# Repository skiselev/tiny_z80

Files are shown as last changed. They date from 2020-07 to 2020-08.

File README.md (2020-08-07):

# Tiny Z80
Business Card Sized Zilog Z80 Single Board Computer

## Table of Content
* [Introduction](#introduction)
* [Specifications](#specifications)
* [Hardware Documentation](#hardware-documentation)
  * [Schematic and PCB Layout](#schematic-and-pcb-layout)
  * [Connectors and Jumpers](#connectors-and-jumpers)
  * [Bill of Materials](#bill-of-materials)
* [Firmware Documentation](#firmware-documentation)
  * [BIOS and OS](#bios-and-os)
  * [SPLD Fuse Map](#spld-fuse-map)
* [Release Notes](#release-notes)
  * [Changes](#changes)
  * [Known Issues](#known-issues)
  * [Wishlist](#wishlist)

## Introduction
Tiny Z80 is a business card sized (size?!) single board computer (SBC). It is mostly compatible with [Easy Z80](https://github.com/skiselev/easy_z80), and offers similar capabilities, including 512 KiB of battery-backed SRAM, 512 KiB Flash ROM, Z80 SIO and Z80 CTC (integrated in Z80 EIPC). Tiny Z80 includes a USB to Serial converter IC on board connected to one of the SIO ports, for ease of use with modern computers. The glue logic, including the memory paging registers is implemented using Altera MAX7000AE CPLD.

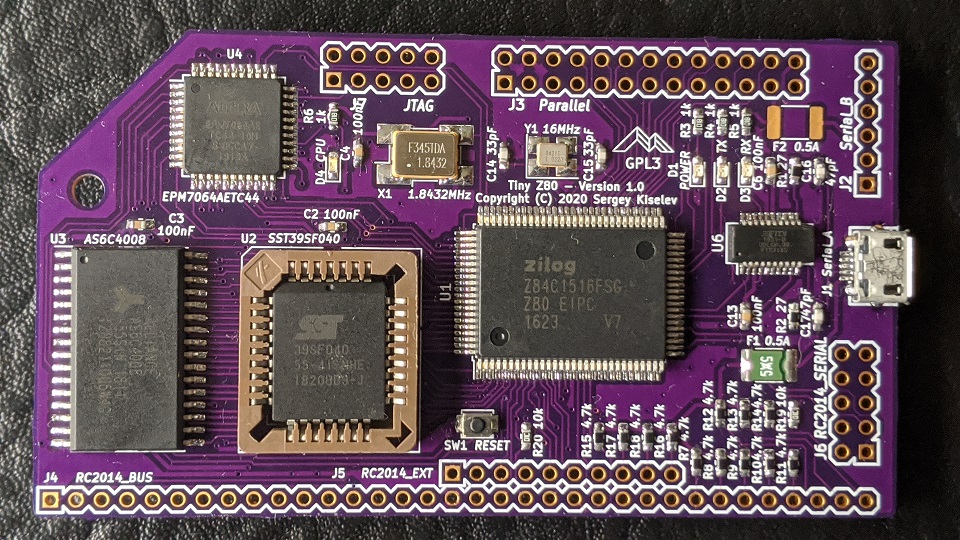
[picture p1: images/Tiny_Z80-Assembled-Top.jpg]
Tiny Z80 Assembled Board Top View


## Specifications
* Processor: Zilog Z80 EIPC - Z84C15, includes Z80 CPU, Z80 SIO, Z80 PIO, and Z80 CTC
* Memory: 512 KiB battery-backed SRAM, 512 KiB Flash ROM
* Input/Output:
  * Dual RS232 serial ports, implemented using Z80 SIO integrated into Z80 EIPC
  * FT231XS USB to Serial converter connected to SIO Port A
  * Two 8-bit parallel ports, implemented using Z80 PIO integrated into Z80 EIPC
  * User controllable LED
* Bus: [RC2014](https://rc2014.co.uk/) compatible
* Microprocessor Supervisor:
  * Reset generation
  * SRAM battery backup
  * Power failure NMI
  * Watchdog (optional)

## Hardware Documentation

### Schematic and PCB Layout

[Schematic - Version 1.0](KiCad/Tiny_Z80-Schematic-1.0.pdf)

[PCB Layout - Version 1.0](KiCad/Tiny_Z80-Board-1.0.pdf)

### Connectors and Jumpers

#### J1 - Serial_A - USB Serial
Pin  | Signal Name | Description
---- | ----------- | -----------
1    | VBUS        | Power Supply - +5V
2    | D-          | USB Data -
3    | D+          | USB Data +
4    | NC          | Not Connected
5    | GND         | Ground

#### J2 - Serial_B - FTDI Header - TTL Level
Pin  | Signal Name | Description
---- | ----------- | -----------
1    | GND         | Ground
2    | RTS         | RS232 / Request to Send
3    | VSER        | Power Supply - +5V (Optional, if F2 is installed)
4    | RXD         | RS232 / Receive
5    | TXD         | RS232 / Transmit
6    | CTS         | RS232 / Clear to Send

#### J3 - Parallel - PIO
Pin  | Signal Name | Description         | Pin  | Signal Name | Description
---- | ----------- | ------------------- | ---- | ----------- | -----------
1    | VCC         | Power Supply - +5V  | 2    | GND         | Ground
3    | PA0         | Port A - Data 0     | 4    | GND         | Ground
5    | PA1         | Port A - Data 1     | 6    | /BSTB       | Port B - Strobe 
7    | PA2         | Port A - Data 2     | 8    | BRDY        | Port B - Ready
9    | PA3         | Port A - Data 3     | 10   | PB7         | Port B - Data 7
11   | PA4         | Port A - Data 4     | 12   | PB6         | Port B - Data 6
13   | PA5         | Port A - Data 5     | 14   | PB5         | Port B - Data 5
15   | PA6         | Port A - Data 6     | 16   | PB4         | Port B - Data 4
17   | PA7         | Port A - Data 7     | 18   | PB3         | Port B - Data 3
19   | ARDY        | Port A - Ready      | 20   | PB2         | Port B - Data 2
21   | /ASTB       | Port A - Strobe     | 22   | PB1         | Port B - Data 1
23   | GND         | Ground              | 24   | PB0         | Port B - Data 0
25   | GND         | Ground              | 26   | VCC         | Power Supply - +5V

#### J4, J5, J6 - RC2014 Bus
Pin   | Signal Name | Description         | Pin  | Signal Name | Description
----- | ----------- | ------------------- | ---- | ----------- | -----------
J4-1  | A15         | Address A15; Output |      |             |
J4-2  | A14         | Address A14; Output |      |             |
J4-3  | A13         | Address A13; Output |      |             |
J4-4  | A12         | Address A12; Output |      |             |
J4-5  | A11         | Address A11; Output |      |             |
J4-6  | A10         | Address A10; Output |      |             |
J4-7  | A9          | Address A9; Output  |      |             |
J4-8  | A8          | Address A8; Output  |      |             |
J4-9  | A7          | Address A7; Output  |      |             |
J4-10 | A6          | Address A6; Output  |      |             |
J4-11 | A5          | Address A5; Output  |      |             |
J4-12 | A4          | Address A4; Output  |      |             |
J4-13 | A3          | Address A3; Output  |      |             |
J4-14 | A2          | Address A2; Output  |      |             |
J4-15 | A1          | Address A1; Output  |      |             |
J4-16 | A0          | Address A0; Output  |      |             |
J4-17 | GND         | Ground              | J5-1 | GND         | Ground
J4-18 | VCC         | Power Supply - +5V  | J5-2 | VCC         | Power Supply - +5V
J4-19 | /M1         | Machine Cycle One; Output | J5-3| /RFSH | DRAM refresh; Output
J4-20 | /RESET      | Reset; Output       | J5-4 | N/C         | Not connected
J4-21 | CPU_CLK     | CPU Clock; Output   | J5-5 | UART_CLK    | UART Clock (1.8432 MHz); Output
J4-22 | /INT        | Interrupt; Input    | J5-6 | /BUSACK     | DMA Bus Acknowledge; Output
J4-23 | /MREQ       | Memory Request; Output | J5-8 | /HALT    | Halt; Output
J4-24 | /WR         | Write Request; Output | J5-9 | /WAIT     | Wait; Input
J4-25 | /RD         | Read Request; Output | J5-10 | /NMI      | Non-maskable Interrupt; Input
J4-26 | /IORQ       | Input/Output Request; Output | |         |
J4-27 | D0          | Data D0; Input/Output |    |             |
J4-28 | D1          | Data D1; Input/Output |    |             |
J4-29 | D2          | Data D2; Input/Output |    |             |
J4-30 | D3          | Data D3; Input/Output |    |             |
J4-31 | D4          | Data D4; Input/Output |    |             |
J4-32 | D5          | Data D5; Input/Output |    |             |
J4-33 | D6          | Data D6; Input/Output |    |             |
J4-34 | D7          | Data D7; Input/Output |    |             |
J6-1  | TXDA        | Channel A, Transmit Data; Output | J6-2 | TXDB | Channel B, Transmit Data; Output
J6-3  | RXDA        | Channel A, Receive Data; Input   | J6-4 | RXDB | Channel B, Receive Data; Input
J6-5  | USR1        | User Pin 1, Not connected | J6-6 | USR5  | User Pin 5, Not connected 
J6-7  | IEI         | Interrupt Enable Input  | J6-8 | USR6    | User Pin 6, Not connected 
J6-9  | IEO         | Interrupt Enable Output | J6-10 | USR7    | User Pin 7, Not connected 

#### J7 - JTAG - CPLD
Pin  | Signal Name | Description      | Pin  | Signal Name | Description
---- | ----------- | ---------------- | ---- | ----------- | ----------------
1    | TCK         | Test Clock       | 2    | GND         | Ground
3    | TDO         | Test Data Output | 4    | 3.3V        | Power Supply - +3.3V
5    | TMS         | Test Mode Select | 6    | NC          | No Connect
7    | NC          | No Connect       | 8    | NC          | No Connect
9    | TDI         | Test Data Input  | 10   | GND         | Ground

#### JP1 - Serial Channel A Clock Select
Position        | Description
--------------- | -----------
*1-2 (default)* | 1.8432 MHz (115200 bps if using x16 mode)
2-3             | Programmable using CTC channel 0

#### JP2 - Serial Channel B Clock Select
Position        | Description
--------------- | -----------
*1-2 (default)* | 1.8432 MHz (115200 bps if using x16 mode)
2-3             | Programmable using CTC channel 1

#### JP3 - LDO Bypass
Solder instead of U7 LDO when using a 5V CPLD

#### JP4 - RAM_CS, JP5 - VRAM
Solder when not using U5 CPU Supervisor to connect RAM_CS and VCC directly to the SRAM IC

### Bill of Materials

#### Version 1.0

[Tiny Z80 project on Mouser.com](https://www.mouser.com/ProjectManager/ProjectDetail.aspx?AccessID=d29f509257) - View and order all components except of the PCB.

[Tiny Z80 project on OSH Park](https://oshpark.com/shared_projects/C0KRm6BH) - View and order the PCB.

Component type     | Reference | Description                                 | Quantity | Possible sources and notes 
------------------ | --------- | ------------------------------------------- | -------- | --------------------------
PCB                |           | Tiny Z80 PCB - Version 1.0                  | 1        | Order from a PCB manufacturer of your choice using provided Gerber or KiCad files
Battery Holder     | BT1       | CR2032 Keystone Electronics 534-1058        | 1        | Mouser [534-1058](https://www.mouser.com/ProductDetail/534-1058)
Battery            | BT1       | CR2032                                      | 1        | 
Capacitor          | C1 - C13  | 100nF 0603 SMT                              | 13       | Mouser [77-VJ0603Y104JXJPBC](https://www.mouser.com/ProductDetail/77-VJ0603Y104JXJPBC)
Capacitor          | C14, C15  | 33pF 0603 SMT                               | 2        | Mouser [77-VJ0603A330JXACBC](https://www.mouser.com/ProductDetail/77-VJ0603A330JXACBC)
Capacitor          | C16, C17  | 47pF 0603 SMT                               | 2        | Mouser [77-VJ0603A470JXACBC](https://www.mouser.com/ProductDetail/77-VJ0603A470JXACBC)
Capacitor          | C18       | 10nF	0603 SMT                               | 1        | Mouser [77-V0603Y103KXJAC31X](https://www.mouser.com/ProductDetail/77-V0603Y103KXJAC31X)
Capacitor          | C20, C19  | 10uF	1210 SMT                               | 2        | Mouser [581-TAJB106K020SNJ](https://www.mouser.com/ProductDetail/581-TAJB106K020SNJ)
Capacitor          | C21       | 47uF	SMT                                    | 1        | Mouser [581-TAJC476K016TNJ](https://www.mouser.com/ProductDetail/581-TAJC476K016TNJ)
LED                | D1        | 0603 SMT Power/Green                        | 1        | Mouser [78-VLMG1300-GS08](https://www.mouser.com/ProductDetail/78-VLMG1300-GS08)
LED                | D2        | 0603 SMT TX/Red                             | 1        | Mouser [78-VLMS1300-GS08](https://www.mouser.com/ProductDetail/78-VLMS1300-GS08), [78-VLMO1300-GS08](https://www.mouser.com/ProductDetail/78-VLMO1300-GS08)
LED                | D3        | 0603 SMT RX/Yellow                          | 1        | Mouser [78-VLMY1300-GS08](https://www.mouser.com/ProductDetail/78-VLMY1300-GS08)
LED                | D4        | 0603 SMT CPU/Blue                           | 1        | Mouser []()
Polyfuse           | F2, F1    | 0.5A	SMT                                    | 2        | Mouser [650-MINISMDC050F-2](https://www.mouser.com/ProductDetail/650-MINISMDC050F-2) 
Connector          | J1        | Mini USB B                                  | 1        | Mouser [649-10118194-0001LF](https://www.mouser.com/ProductDetail/649-10118194-0001LF)
Connector          | J2        | Pin Header 1x6                              | 1        | 
Connector          | J3        | Pin Header 2x13                             | 1        | 
Connector          | J4, J5    | Pin Header 2x34, Right Angle                | 1        | Mouser [571-9-103326-0](https://www.mouser.com/ProductDetail/571-9-103326-0) Note: Cut to 34 pin, remove extra pins. Use remaining 2x6 piece for J6
Connector          | J6, J7    | Pin Header 2x5                              | 2        | 
Resistor           | R1, R2    | 27	Ohm 0603 SMT                             | 2        | Mouser [71-CRCW0603-27-E3](https://www.mouser.com/ProductDetail/71-CRCW0603-27-E3)
Resistor           | R3 - R6   | 1 kOhm 0603 SMT                             | 4        | Mouser [71-CRCW0603-1.0K-E3](https://www.mouser.com/ProductDetail/71-CRCW0603-1.0K-E3)
Resistor           | R7 - R18  | 4.7 kOhm	0603 SMT                           | 12       | Mouser [71-CRCW0603-4.7K-E3](https://www.mouser.com/ProductDetail/71-CRCW0603-4.7K-E3)
Resistor           | R19 - R25 | 10 kOhm 0603 SMT                            | 7        | Mouser [71-CRCW0603-10K-E3](https://www.mouser.com/ProductDetail/71-CRCW0603-10K-E3) 
Resistor           | R26       | 29.4 kOhm 0603 SMT                          | 1        | Mouser [71-CRCW0603-29.4K-E3](https://www.mouser.com/ProductDetail/71-CRCW0603-29.4K-E3)
Trimmer Resistor   | RV1       | 2 kOhm                                      | 1        | Mouser [652-TC33X-2-202E](https://www.mouser.com/ProductDetail/652-TC33X-2-202E), [81-PVG3G202C01R00](https://www.mouser.com/ProductDetail/81-PVG3G202C01R00)
Tactile Switch     | SW1       | Tactile Switch                              | 1        | Mouser [653-B3U-1000P](https://www.mouser.com/ProductDetail/653-B3U-1000P)
Integrated Circuit | U1        | Z84C15, Zilog Z80 EIPC, 16 MHz, QFP-100     | 1        | Mouser [692-Z84C1516FSG](https://www.mouser.com/ProductDetail/692-Z84C1516FSG)
Integrated Circuit | U2        | SST39SF040, 512 KiB Flash ROM, PLCC-32      | 1        | Mouser [579-39SF0405INHE](https://www.mouser.com/ProductDetail/579-39SF0405INHE)
Integrated Circuit | U3        | AS6C4008, 512 KiB SRAM, SOP-32              | 1        | Mouser [913-AS6C4008-55SIN](https://www.mouser.com/ProductDetail/913-AS6C4008-55SIN)
Integrated Circuit | U4        | EPM7064AETC44, Altera MAX 7000AE CPLD, TQFP-44 | 1        | Mouser [989-EPM7064AETC4410N](https://www.mouser.com/ProductDetail/989-EPM7064AETC4410N)
Integrated Circuit | U5        | MAX691xWE                                   | 1        | Mouser [584-ADM691AARWZ-R](https://www.mouser.com/ProductDetail/584-ADM691AARWZ-R)
Integrated Circuit | U6        | FT231XS                                     | 1        | Mouser [895-FT231XS-R](https://www.mouser.com/ProductDetail/895-FT231XS-R)
Integrated Circuit | U7        | TPS79333-EP                                 | 1        | Mouser [595-TPS79333DBVR](https://www.mouser.com/ProductDetail/595-TPS79333DBVR)
IC Socket          | U2        | PLCC32 SMD Socket                           | 1        | Mouser [649-69802-432LF](https://www.mouser.com/ProductDetail/649-69802-432LF)
Crystal Oscillator | X1        | 1.8432 MHz XO91                             | 1        | Mouser [559-F3345-184](https://www.mouser.com/ProductDetail/559-F3345-184)
Crystal Resonator  | Y1        | 16 MHz Crystal_GND24                        | 1        | Mouser [732-22516MF18X-G](https://www.mouser.com/ProductDetail/732-22516MF18X-G)

## Firmware Documentation

### BIOS and OS

Tiny Z80 is supported by [RomWBW](https://github.com/wwarthen/RomWBW) [v3.0.1](https://github.com/wwarthen/RomWBW/releases/tag/v3.0.1) and later. RomWBW includes BIOS, CP/M-80 2.2, Z-System, and a collection of utilities. It also should be possible to run [FUZIX](https://github.com/EtchedPixels/FUZIX) on this board.
*Note: Edit Easy Z80 configuration (cfg_ezz80.asm), set SIO0BASE to $18 and CTCBASE	to $10*

### CPLD Fuse Map

Tiny Z80 uses an Intel/Altera EPM7064AETC44 CPLD (U4) for address decode logic. The [CPLD fuse map](CPLD/tiny_z80.pof) and the CPLD source code are provided in [CPLD](CPLD) directory of this repository. Use free Altera Quartus II 13.0sp1 Web Edition to program the CPLD. Newer Quartus versions do not support Altera MAX7000 CPLDs.

## Release Notes

### Changes
* Version 1.0
  * Initial version

### Known Issues
* Version 1.0
  * Front silkscreen: J7 overlaps with 100nF value of C4
  
### Wishlist
* Version 1.0
  * None

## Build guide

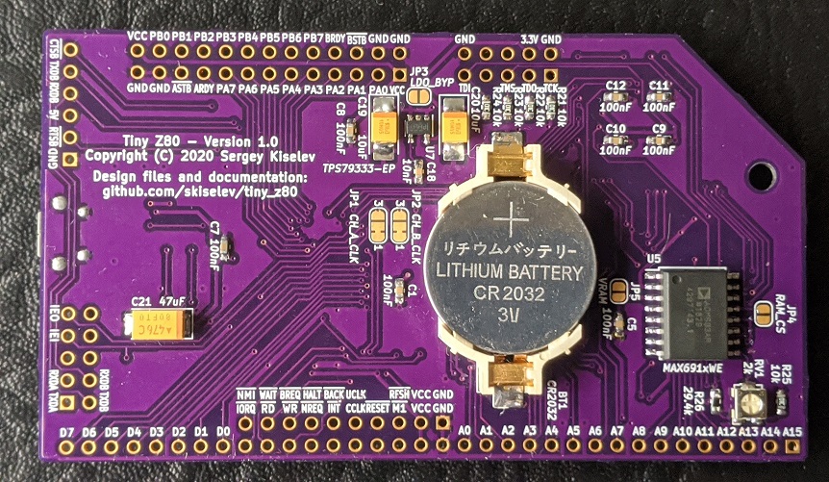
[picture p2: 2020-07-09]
images/Tiny_Z80-Assembled-Bottom.jpg

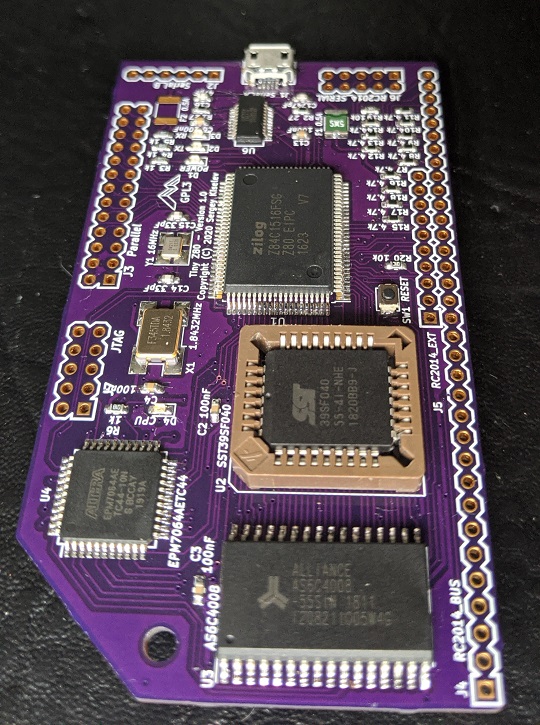
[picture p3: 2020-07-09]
images/Tiny_Z80-Assembled-Side.jpg

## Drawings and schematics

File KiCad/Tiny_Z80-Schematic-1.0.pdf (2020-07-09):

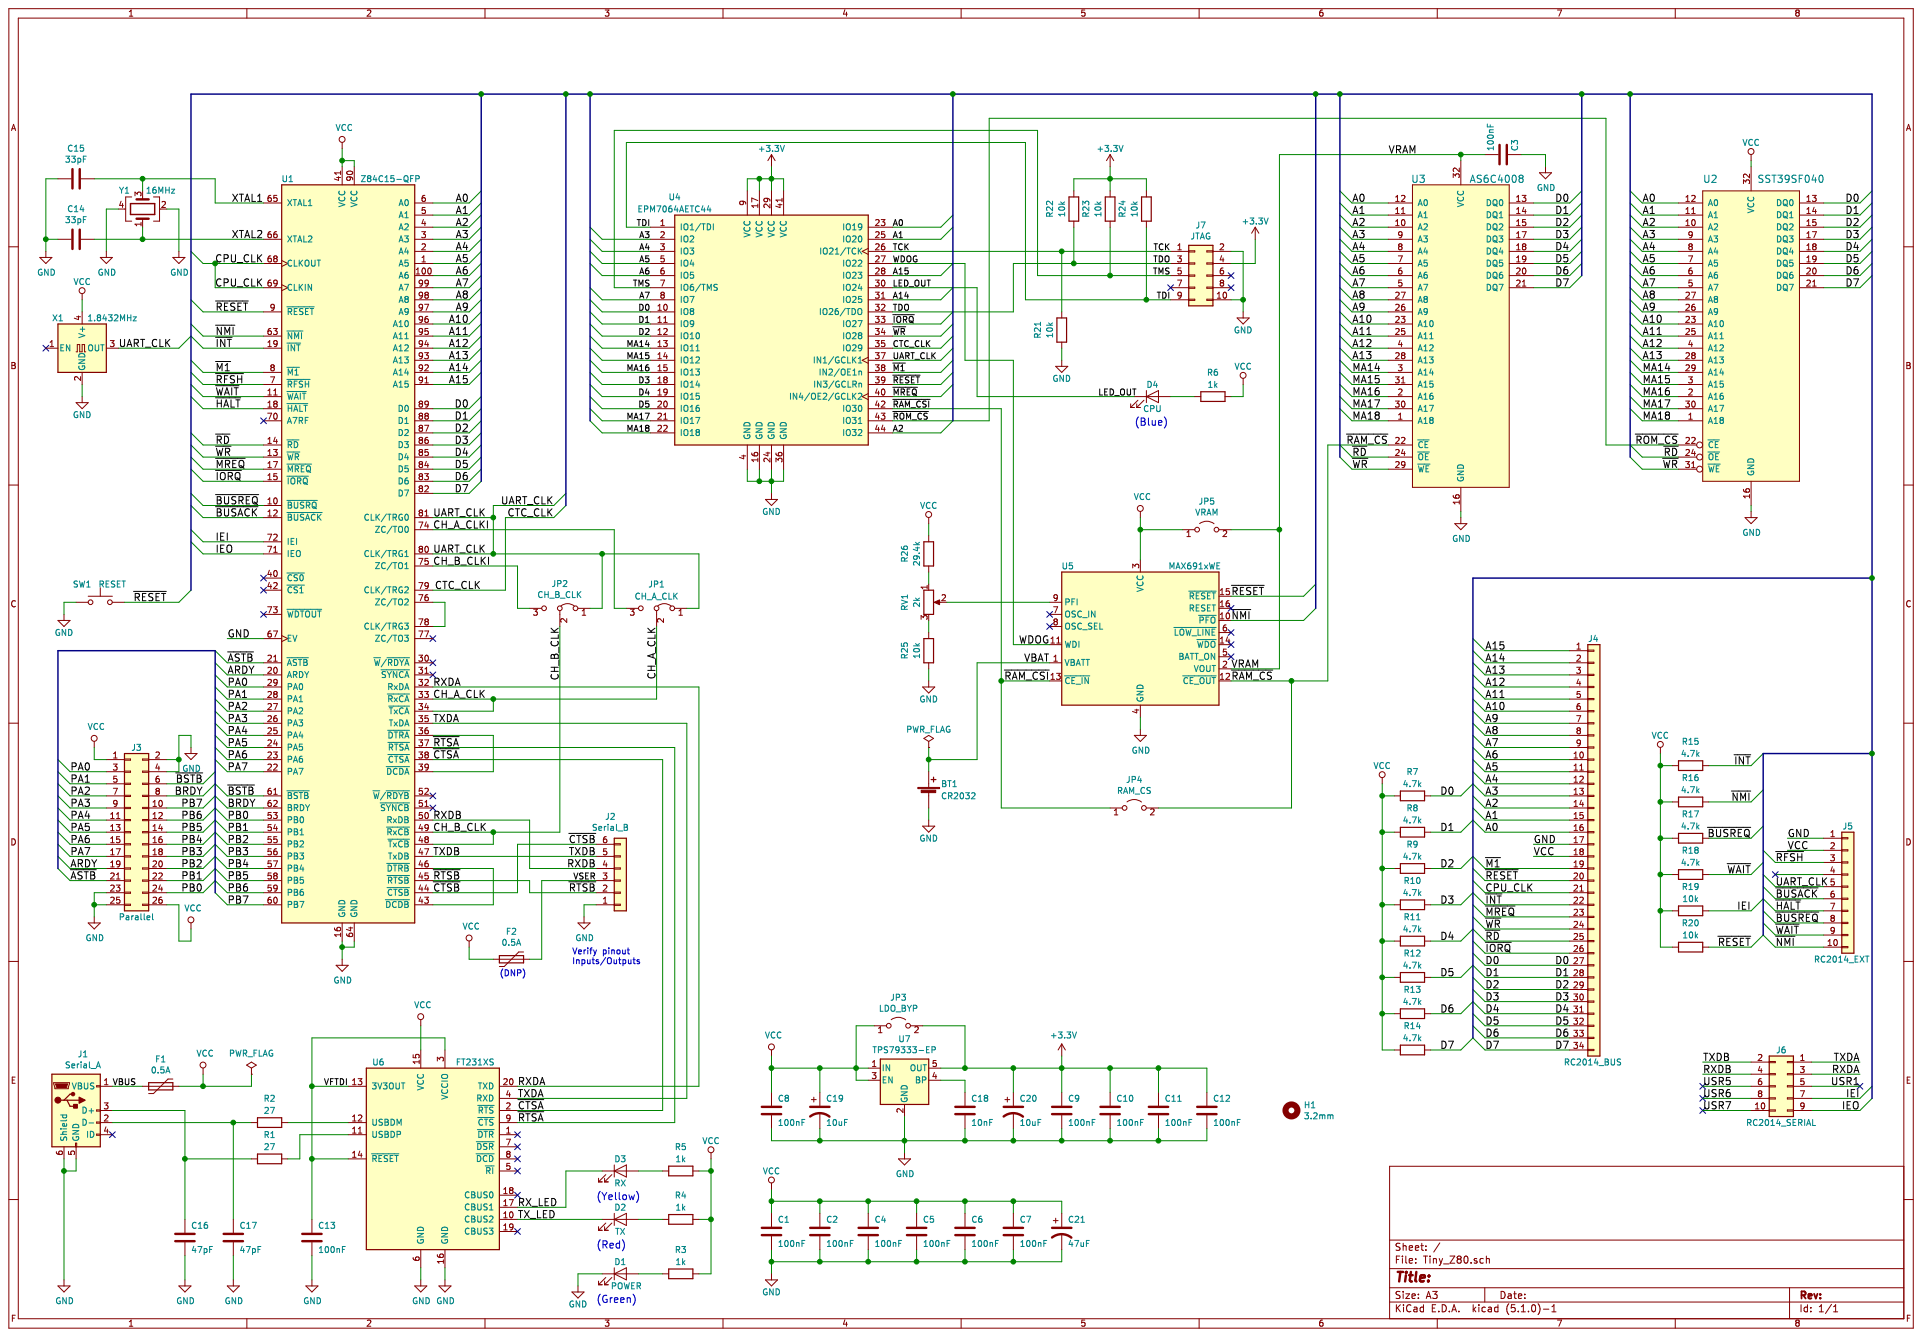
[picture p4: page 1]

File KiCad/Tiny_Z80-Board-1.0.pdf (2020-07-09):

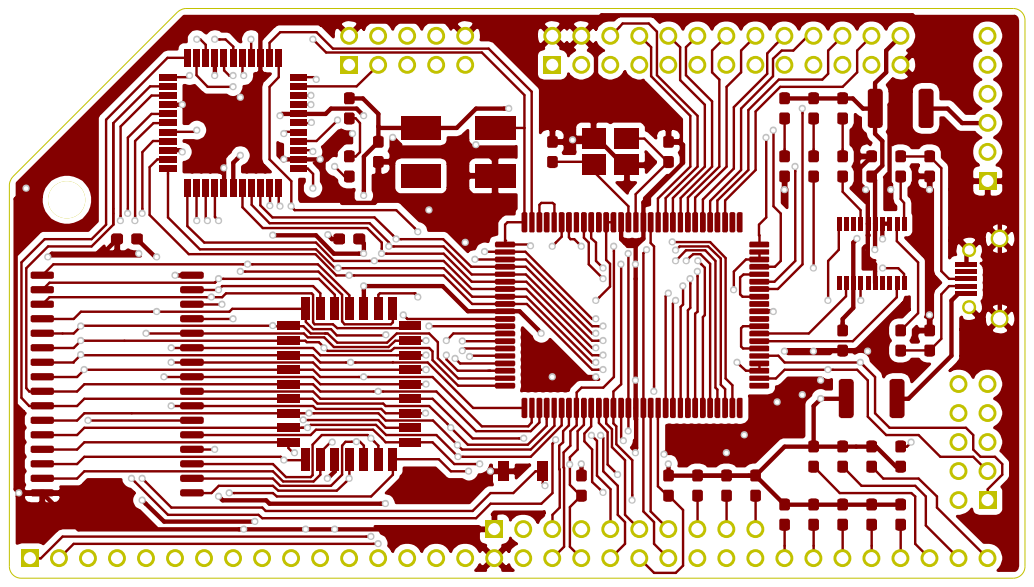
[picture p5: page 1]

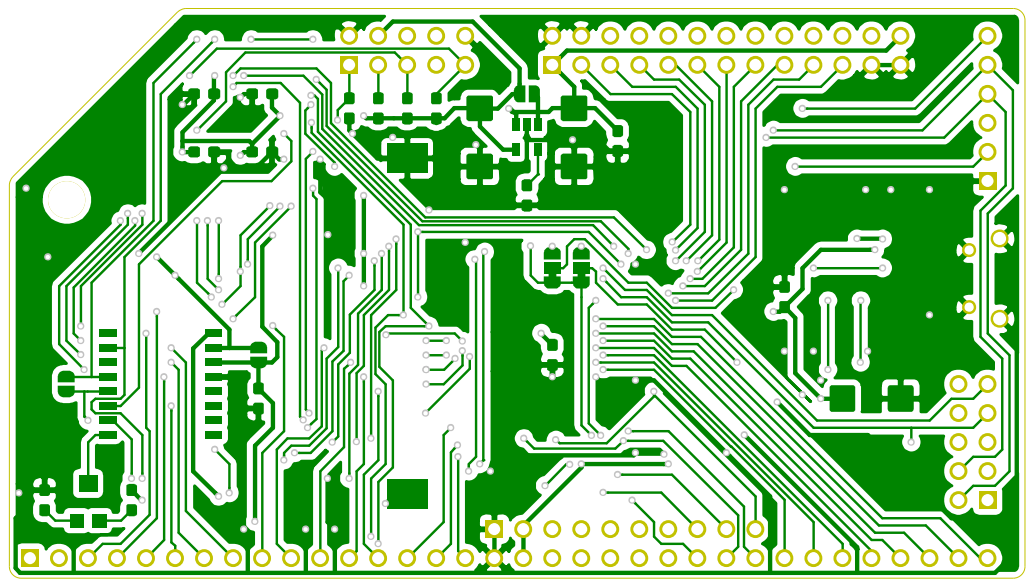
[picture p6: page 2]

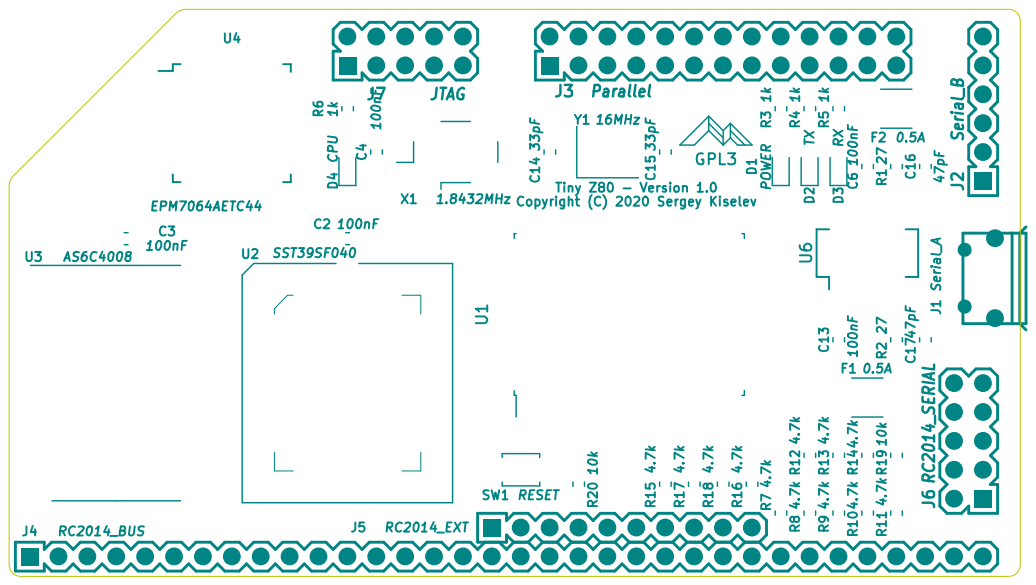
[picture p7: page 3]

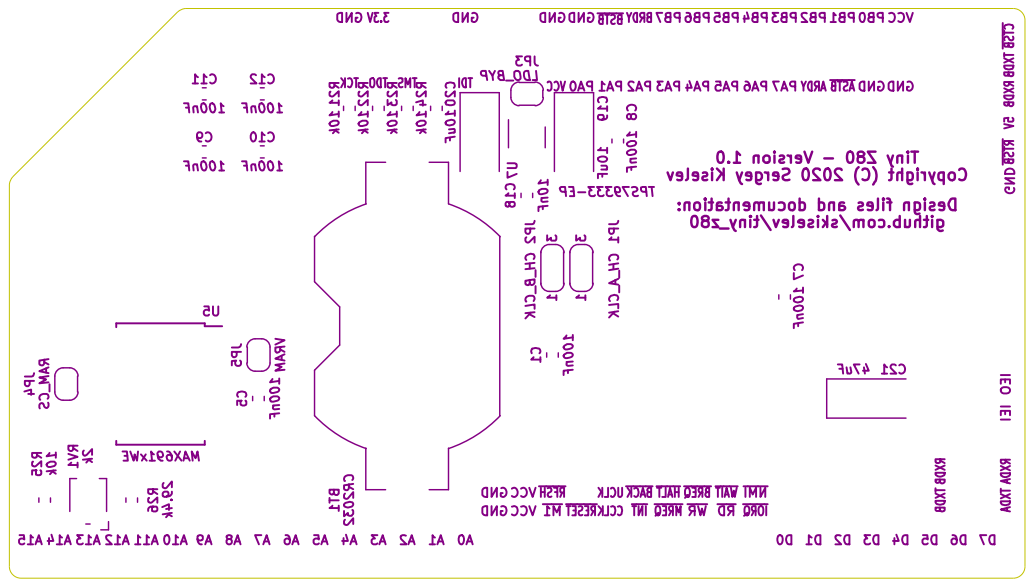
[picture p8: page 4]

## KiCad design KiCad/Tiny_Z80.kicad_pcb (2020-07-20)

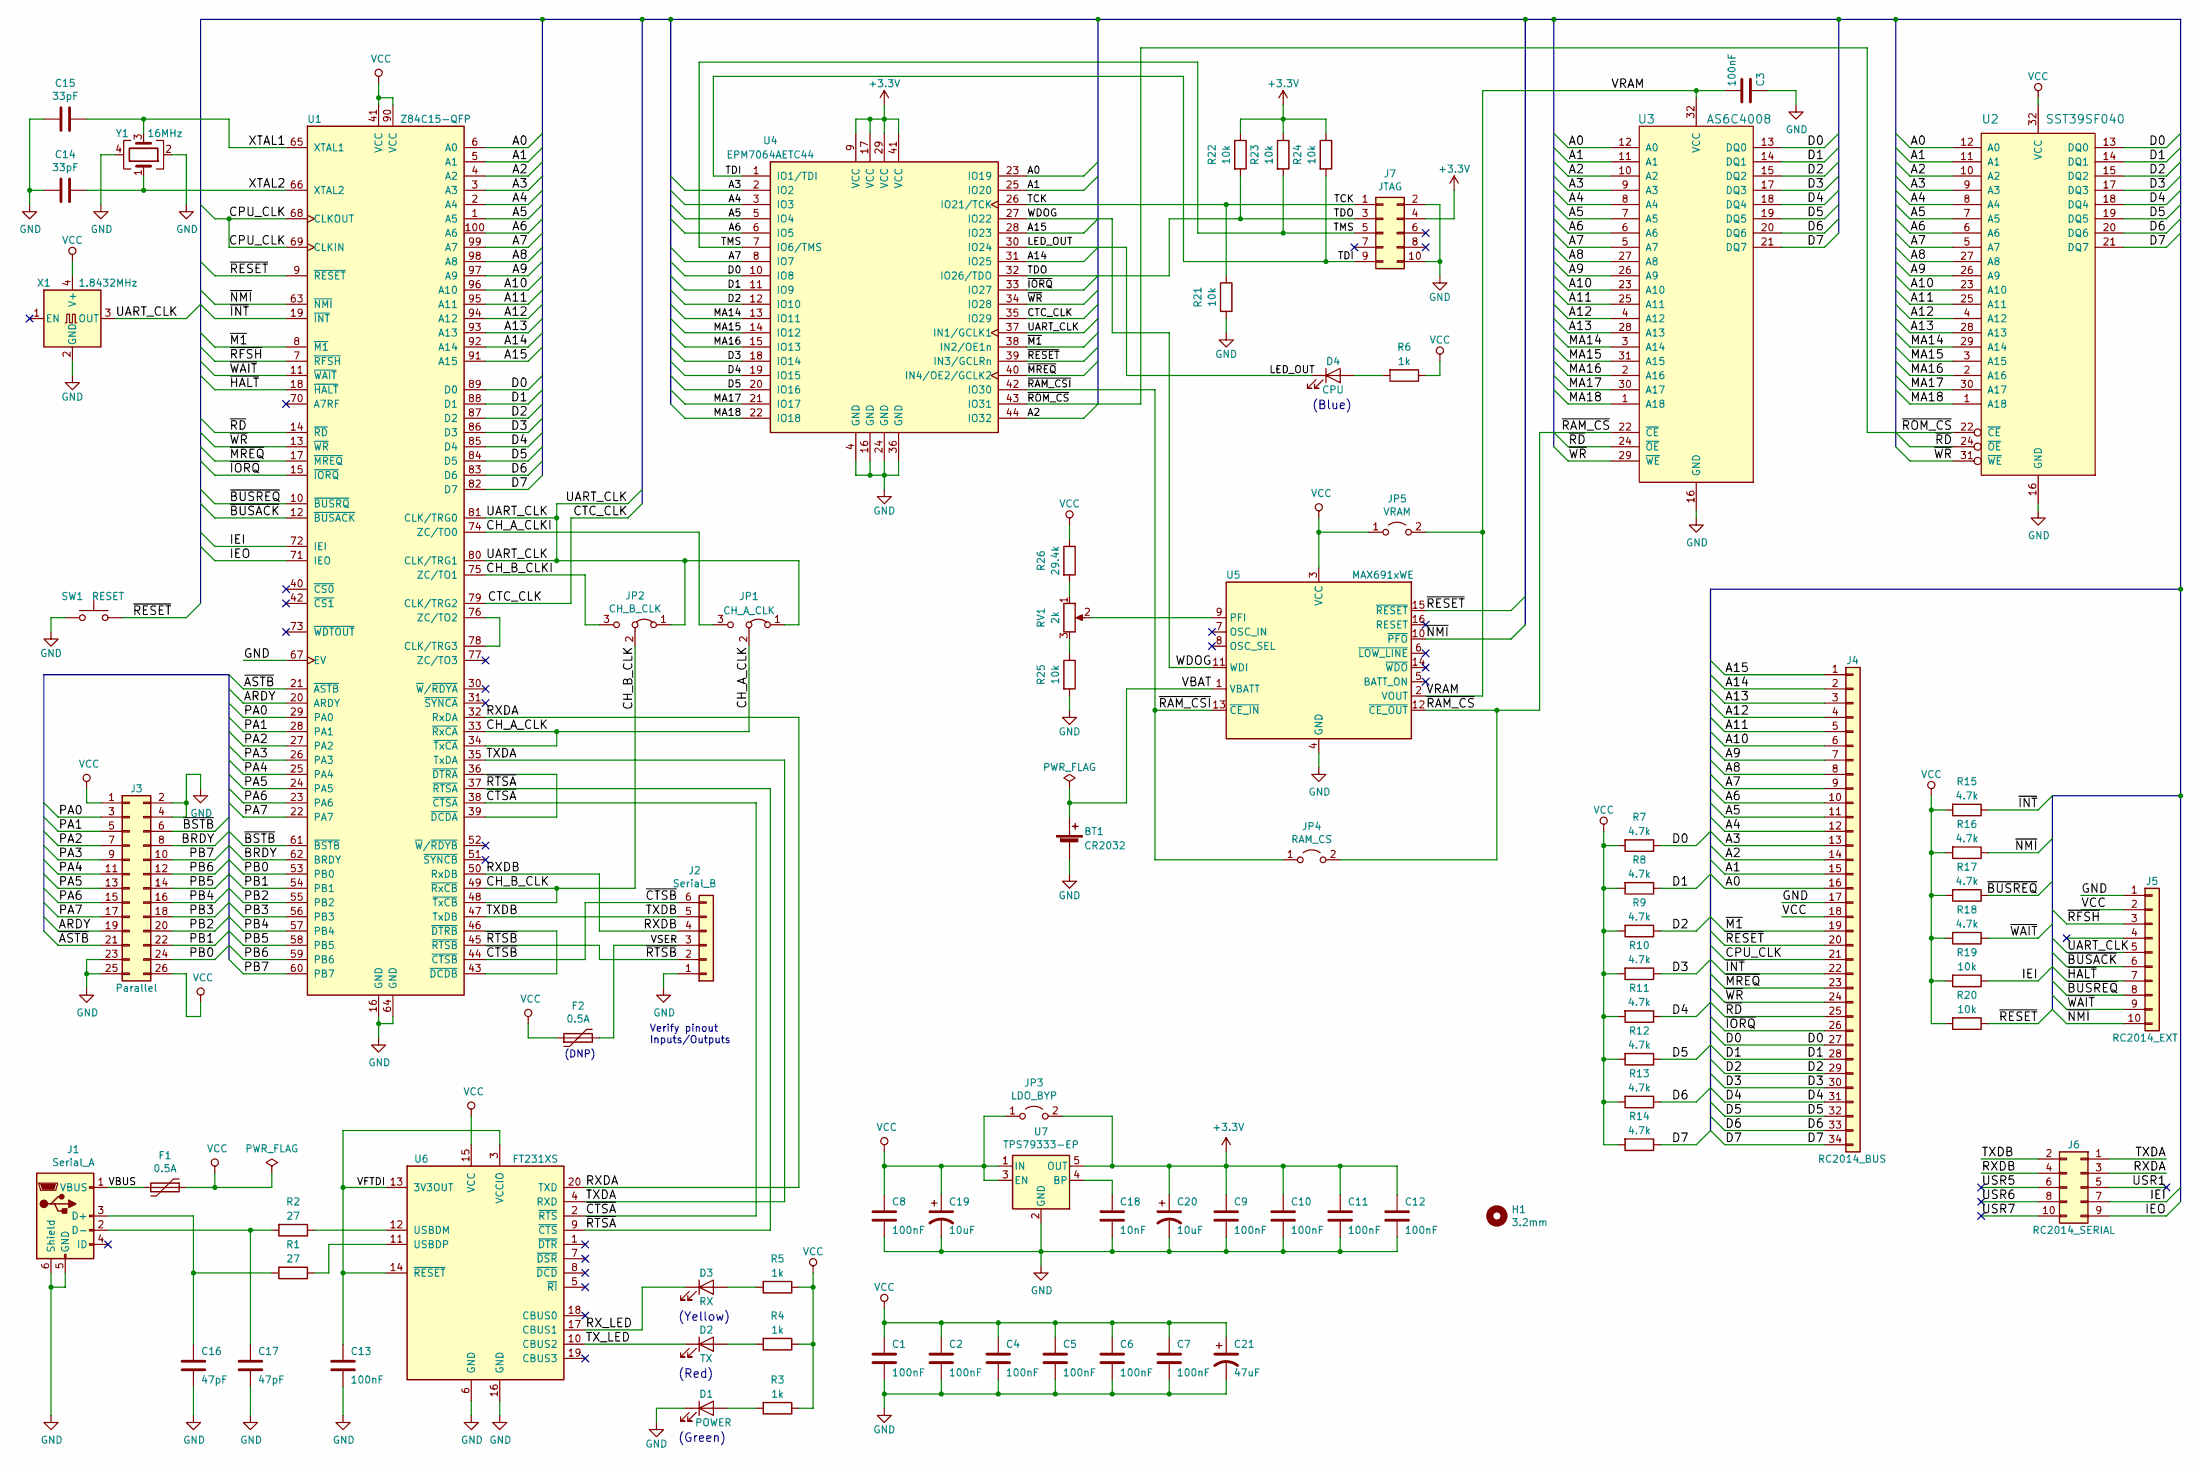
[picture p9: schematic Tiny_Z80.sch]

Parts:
BT1: CR2032; BatteryHolder_Keystone_1058_1x2032
C1, C2, C3, C4, C5, C6, C7, C8, C9, C10, C11, C12, C13: 100nF; C_0603_1608Metric_Pad1.05x0.95mm_HandSolder
C14, C15: 33pF; C_0603_1608Metric_Pad1.05x0.95mm_HandSolder
C16, C17: 47pF; C_0603_1608Metric_Pad1.05x0.95mm_HandSolder
C18: 10nF; C_0603_1608Metric_Pad1.05x0.95mm_HandSolder
C19, C20: 10uF; CP_EIA-6032-28_Kemet-C_Pad2.25x2.35mm_HandSolder
C21: 47uF; CP_EIA-6032-28_Kemet-C_Pad2.25x2.35mm_HandSolder
D1: POWER; LED_0603_1608Metric_Pad1.05x0.95mm_HandSolder
D2: TX; LED_0603_1608Metric_Pad1.05x0.95mm_HandSolder
D3: RX; LED_0603_1608Metric_Pad1.05x0.95mm_HandSolder
D4: CPU; LED_0603_1608Metric_Pad1.05x0.95mm_HandSolder
F1, F2: 0.5A; Fuse_1812_4532Metric_Pad1.30x3.40mm_HandSolder
H1: 3.2mm; MountingHole_3.2mm_M3_DIN965
J1: Serial_A; Conn_Micro_USB_B
J2: Serial_B; Conn_Pin_Header_6x1_2.54mm
J3: Parallel; Conn_Pin_Header_13x2_2.54mm
J4: RC2014_BUS; Conn_Pin_Header_34x1_2.54mm
J5: RC2014_EXT; Conn_Pin_Header_10x1_2.54mm
J6: RC2014_SERIAL; Conn_Pin_Header_5x2_2.54mm
J7: JTAG; Conn_Pin_Header_5x2_2.54mm
JP1: CH_A_CLK; SolderJumper-3_P1.3mm_Bridged12_RoundedPad1.0x1.5mm_NumberL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
JP2: CH_B_CLK; SolderJumper-3_P1.3mm_Bridged12_RoundedPad1.0x1.5mm_NumberL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
JP3: LDO_BYP; SolderJumper-2_P1.3mm_Open_RoundedPad1.0x1.5mm
JP4: RAM_CS; SolderJumper-2_P1.3mm_Open_RoundedPad1.0x1.5mm
JP5: VRAM; SolderJumper-2_P1.3mm_Open_RoundedPad1.0x1.5mm
R1, R2: 27; R_0603_1608Metric_Pad1.05x0.95mm_HandSolder
R3, R4, R5, R6: 1k; R_0603_1608Metric_Pad1.05x0.95mm_HandSolder
R7, R8, R9, R10, R11, R12, R13, R14, R15, R16, R17, R18: 4.7k; R_0603_1608Metric_Pad1.05x0.95mm_HandSolder
R19, R20, R21, R22, R23, R24, R25: 10k; R_0603_1608Metric_Pad1.05x0.95mm_HandSolder
R26: 29.4k; R_0603_1608Metric_Pad1.05x0.95mm_HandSolder
RV1: 2k; Potentiometer_Bourns_TC33X_Vertical
SW1: RESET; SW_SPST_B3U-1000P
U1: Z84C15-QFP; PQFP-100_14x20mm_P0.65mm
U2: SST39SF040; PLCC-32_SMD-Socket
U3: AS6C4008; SSOP-32_11.305x20.495mm_P1.27mm
U4: EPM7064AETC44; TQFP-44_10x10mm_P0.8mm
U5: MAX691xWE; SOIC-16W_7.5x10.3mm_P1.27mm
U6: FT231XS; SSOP-20_3.9x8.7mm_P0.635mm
U7: TPS79333-EP; SOT-23-5
X1: 1.8432MHz; Oscillator_SMD_EuroQuartz_XO91-4Pin_7.0x5.0mm_HandSoldering
Y1: 16MHz; Crystal_SMD_3225-4Pin_3.2x2.5mm_HandSoldering

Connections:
+3V3: C9.1, C10.1, C11.1, C12.1, C20.1, J7.4, JP3.2 (B), R22.1, R23.1, R24.1, U4.9 (VCC), U4.17 (VCC), U4.29 (VCC), U4.41 (VCC), U7.5 (OUT)
/A0: J4.16, U1.6 (A0), U2.12 (A0), U3.12 (A0), U4.23 (IO19)
/A1: J4.15, U1.5 (A1), U2.11 (A1), U3.11 (A1), U4.25 (IO20)
/A2: J4.14, U1.4 (A2), U2.10 (A2), U3.10 (A2), U4.44 (IO32)
/A3: J4.13, U1.3 (A3), U2.9 (A3), U3.9 (A3), U4.2 (IO2)
/A4: J4.12, U1.2 (A4), U2.8 (A4), U3.8 (A4), U4.3 (IO3)
/A5: J4.11, U1.1 (A5), U2.7 (A5), U3.7 (A5), U4.5 (IO4)
/A6: J4.10, U1.100 (A6), U2.6 (A6), U3.6 (A6), U4.6 (IO5)
/A7: J4.9, U1.99 (A7), U2.5 (A7), U3.5 (A7), U4.8 (IO7)
/A8: J4.8, U1.98 (A8), U2.27 (A8), U3.27 (A8)
/A9: J4.7, U1.97 (A9), U2.26 (A9), U3.26 (A9)
/A10: J4.6, U1.96 (A10), U2.23 (A10), U3.23 (A10)
/A11: J4.5, U1.95 (A11), U2.25 (A11), U3.25 (A11)
/A12: J4.4, U1.94 (A12), U2.4 (A12), U3.4 (A12)
/A13: J4.3, U1.93 (A13), U2.28 (A13), U3.28 (A13)
/A14: J4.2, U1.92 (A14), U4.31 (IO25)
/A15: J4.1, U1.91 (A15), U4.28 (IO23)
/ARDY: J3.19, U1.20 (ARDY)
/BRDY: J3.8, U1.62 (BRDY)
/CH_A_CLK: JP1.2 (C), U1.33 (~RxCA~), U1.34 (~TxCA~)
/CH_A_CLKI: JP1.3 (B), U1.74 (ZC/TO0)
/CH_B_CLK: JP2.2 (C), U1.48 (~TxCB~), U1.49 (~RxCB~)
/CH_B_CLKI: JP2.3 (B), U1.75 (ZC/TO1)
/CPU_CLK: J4.21, U1.68 (CLKOUT), U1.69 (CLKIN)
/CTC_CLK: U1.79 (CLK/TRG2), U4.35 (IO29)
/D0: J4.27, R7.1, U1.89 (D0), U2.13 (DQ0), U3.13 (DQ0), U4.10 (IO8)
/D1: J4.28, R8.1, U1.88 (D1), U2.14 (DQ1), U3.14 (DQ1), U4.11 (IO9)
/D2: J4.29, R9.1, U1.87 (D2), U2.15 (DQ2), U3.15 (DQ2), U4.12 (IO10)
/D3: J4.30, R10.1, U1.86 (D3), U2.17 (DQ3), U3.17 (DQ3), U4.18 (IO14)
/D4: J4.31, R11.1, U1.85 (D4), U2.18 (DQ4), U3.18 (DQ4), U4.19 (IO15)
/D5: J4.32, R12.1, U1.84 (D5), U2.19 (DQ5), U3.19 (DQ5), U4.20 (IO16)
/D6: J4.33, R13.1, U1.83 (D6), U2.20 (DQ6), U3.20 (DQ6)
/D7: J4.34, R14.1, U1.82 (D7), U2.21 (DQ7), U3.21 (DQ7)
/IEI: J6.7, R19.1, U1.72 (IEI)
/IEO: J6.9, U1.71 (IEO)
/LED_OUT: D4.1 (K), U4.30 (IO24)
/MA14: U2.29 (A14), U3.3 (A14), U4.13 (IO11)
/MA15: U2.3 (A15), U3.31 (A15), U4.14 (IO12)
/MA16: U2.2 (A16), U3.2 (A16), U4.15 (IO13)
/MA17: U2.30 (A17), U3.30 (A17), U4.21 (IO17)
/MA18: U2.1 (A18), U3.1 (A18), U4.22 (IO18)
/PA0: J3.3, U1.29 (PA0)
/PA1: J3.5, U1.28 (PA1)
/PA2: J3.7, U1.27 (PA2)
/PA3: J3.9, U1.26 (PA3)
/PA4: J3.11, U1.25 (PA4)
/PA5: J3.13, U1.24 (PA5)
/PA6: J3.15, U1.23 (PA6)
/PA7: J3.17, U1.22 (PA7)
/PB0: J3.24, U1.53 (PB0)
/PB1: J3.22, U1.54 (PB1)
/PB2: J3.20, U1.55 (PB2)
/PB3: J3.18, U1.56 (PB3)
/PB4: J3.16, U1.57 (PB4)
/PB5: J3.14, U1.58 (PB5)
/PB6: J3.12, U1.59 (PB6)
/PB7: J3.10, U1.60 (PB7)
/RXDA: J6.3, U1.32 (RxDA), U6.20 (TXD)
/RXDB: J2.4, J6.4, U1.50 (RxDB)
/RX_LED: D3.1 (K), U6.17 (CBUS1)
/TCK: J7.1, R21.1, U4.26 (IO21/TCK)
/TDI: J7.9, R24.2, U4.1 (IO1/TDI)
/TDO: J7.3, R22.2, U4.32 (IO26/TDO)
/TMS: J7.5, R23.2, U4.7 (IO6/TMS)
/TXDA: J6.1, U1.35 (TxDA), U6.4 (RXD)
/TXDB: J2.5, J6.2, U1.47 (TxDB)
/TX_LED: D2.1 (K), U6.10 (CBUS2)
/UART_CLK: J5.5, JP1.1 (A), JP2.1 (A), U1.80 (CLK/TRG1), U1.81 (CLK/TRG0), U4.37 (IN1/GCLK1), X1.3 (OUT)
/USR1: J6.5
/USR5: J6.6
/USR6: J6.8
/USR7: J6.10
/VBAT: BT1.1 (+), U5.1 (VBATT)
/VBUS: F1.2, J1.1 (VBUS)
/VFTDI: C13.1, U6.3 (VCCIO), U6.13 (3V3OUT), U6.14 (~RESET)
/VRAM: C3.2, JP5.2 (B), U3.32 (VCC), U5.2 (VOUT)
/VSER: F2.2, J2.3
/WDOG: U4.27 (IO22), U5.11 (WDI)
/XTAL1: C15.1, U1.65 (XTAL1), Y1.3
/XTAL2: C14.1, U1.66 (XTAL2), Y1.1
/~ASTB~: J3.21, U1.21 (~ASTB~)
/~BSTB~: J3.6, U1.61 (~BSTB~)
/~BUSACK: J5.6, U1.12 (~BUSACK~)
/~BUSREQ: J5.8, R17.1, U1.10 (~BUSRQ~)
/~CTSA: U1.38 (~CTSA~), U6.2 (~RTS)
/~CTSB: J2.6, U1.44 (~CTSB~)
/~HALT: J5.7, U1.18 (~HALT~)
/~INT: J4.22, R15.1, U1.19 (~INT~)
/~IORQ: J4.26, U1.15 (~IORQ~), U4.33 (IO27)
/~M1: J4.19, U1.8 (~M1~), U4.38 (IN2/OE1n)
/~MREQ: J4.23, U1.17 (~MREQ~), U4.40 (IN4/OE2/GCLK2)
/~NMI: J5.10, R16.1, U1.63 (~NMI~), U5.10 (~PFO)
/~RAM_CS: JP4.2 (B), U3.22 (~CE), U5.12 (~CE_OUT)
/~RAM_CSI: JP4.1 (A), U4.42 (IO30), U5.13 (~CE_IN)
/~RD: J4.25, U1.14 (~RD~), U2.24 (~OE), U3.24 (~OE)
/~RESET: J4.20, R20.1, SW1.1, U1.9 (~RESET~), U4.39 (IN3/GCLRn), U5.15 (~RESET)
/~RFSH: J5.3, U1.7 (~RFSH~)
/~ROM_CS: U2.22 (~CE), U4.43 (IO31)
/~RTSA: U1.37 (~RTSA~), U6.9 (~CTS)
/~RTSB: J2.2, U1.45 (~RTSB~)
/~WAIT: J5.9, R18.1, U1.11 (~WAIT~)
/~WR: J4.24, U1.13 (~WR~), U2.31 (~WE), U3.29 (~WE), U4.34 (IO28)
GND: BT1.2 (-), C1.2, C2.2, C3.1, C4.2, C5.2, C6.2, C7.2, C8.2, C9.2, C10.2, C11.2, C12.2, C13.2, C14.2, C15.2, C16.2, C17.2, C18.2, C19.2, C20.2, C21.2, D1.1 (K), J1.5 (GND), J1.6 (Shield), J2.1, J3.2, J3.4, J3.23, J3.25, J4.17, J5.1, J7.2, J7.10, R21.2, R25.2, SW1.2, U1.16 (GND), U1.64 (GND), U1.67 (EV), U2.16 (GND), U3.16 (GND), U4.4 (GND), U4.16 (GND), U4.24 (GND), U4.36 (GND), U5.4 (GND), U6.6 (GND), U6.16 (GND), U7.2 (GND), X1.2 (GND), Y1.2, Y1.4
unnamed: C16.1, J1.3 (D+), R1.2
unnamed: C17.1, J1.2 (D-), R2.2
unnamed: C18.1, U7.4 (BP)
unnamed: D1.2 (A), R3.2
unnamed: D2.2 (A), R4.2
unnamed: D3.2 (A), R5.2
unnamed: D4.2 (A), R6.2
unnamed: R1.1, U6.11 (USBDP)
unnamed: R2.1, U6.12 (USBDM)
unnamed: R25.1, RV1.3
unnamed: R26.2, RV1.1
unnamed: RV1.2, U5.9 (PFI)
unnamed: U1.36 (~DTRA~), U1.39 (~DCDA~)
unnamed: U1.43 (~DCDB~), U1.46 (~DTRB~)
unnamed: U1.76 (ZC/TO2), U1.78 (CLK/TRG3)
VCC: C1.1, C2.1, C4.1, C5.1, C6.1, C7.1, C8.1, C19.1, C21.1, F1.1, F2.1, J3.1, J3.26, J4.18, J5.2, JP3.1 (A), JP5.1 (A), R3.1, R4.1, R5.1, R6.1, R7.2, R8.2, R9.2, R10.2, R11.2, R12.2, R13.2, R14.2, R15.2, R16.2, R17.2, R18.2, R19.2, R20.2, R26.1, U1.41 (VCC), U1.90 (VCC), U2.32 (VCC), U5.3 (VCC), U6.15 (VCC), U7.1 (IN), U7.3 (EN), X1.4 (V+)

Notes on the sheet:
Verify pinout Inputs/Outputs
(DNP)
(Yellow)
(Red)
(Green)
(Blue)

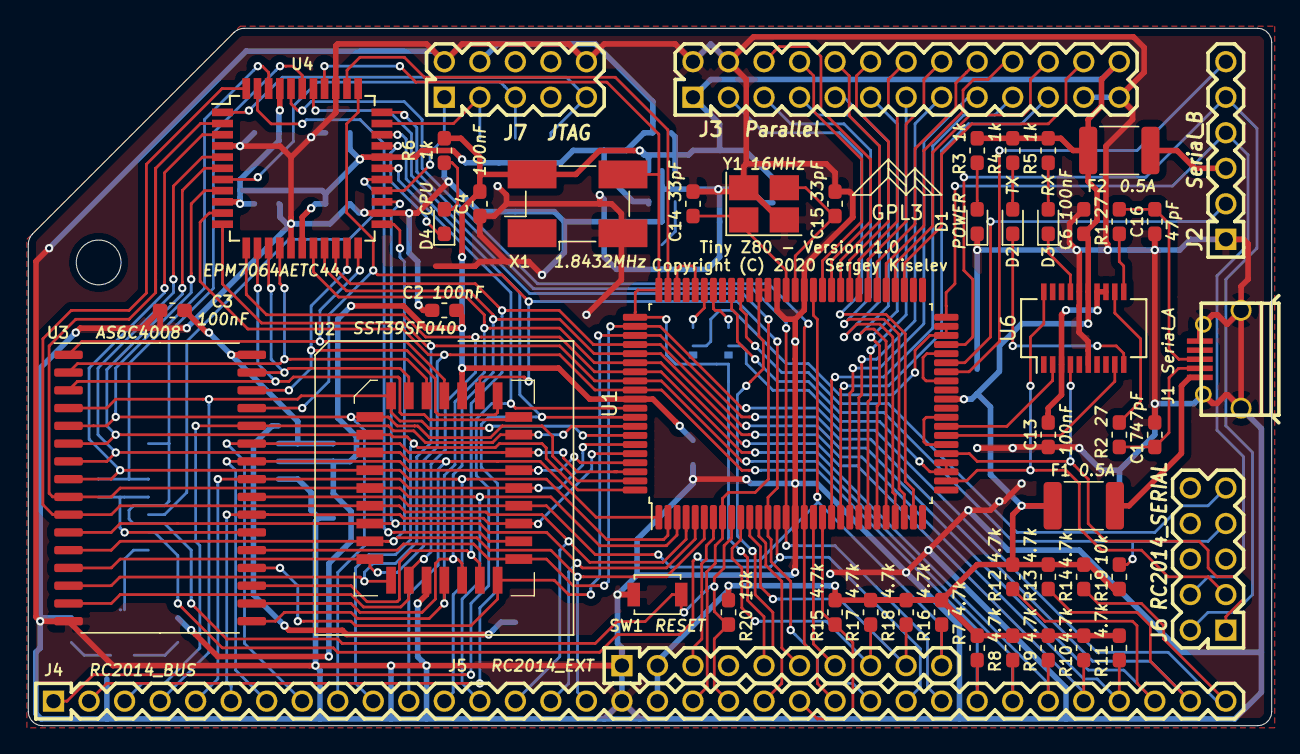
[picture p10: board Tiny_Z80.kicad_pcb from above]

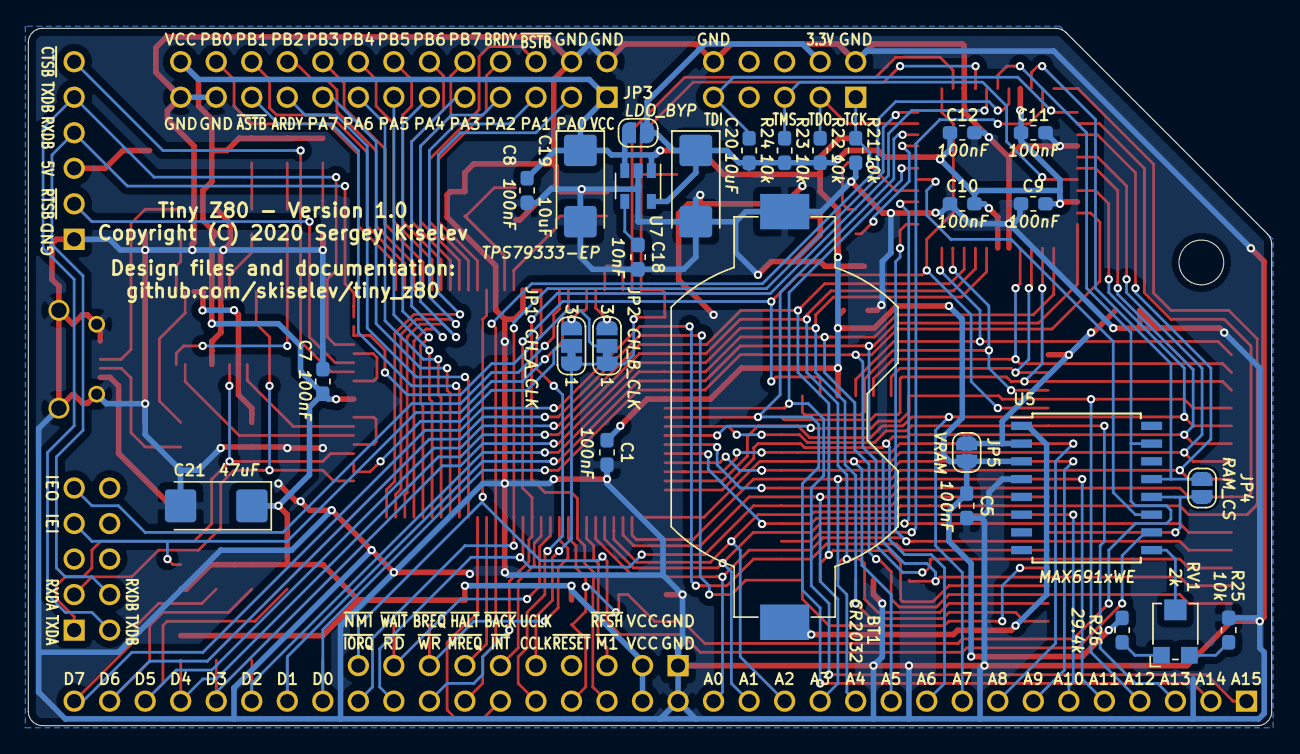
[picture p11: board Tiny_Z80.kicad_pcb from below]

Board: 2 copper layers, 88.9 x 49.9 mm, 78 parts (27 on the bottom side), 115 nets.

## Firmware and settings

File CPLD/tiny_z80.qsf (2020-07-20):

# -------------------------------------------------------------------------- #
#
# Copyright (C) 1991-2012 Altera Corporation
# Your use of Altera Corporation's design tools, logic functions 
# and other software and tools, and its AMPP partner logic 
# functions, and any output files from any of the foregoing 
# (including device programming or simulation files), and any 
# associated documentation or information are expressly subject 
# to the terms and conditions of the Altera Program License 
# Subscription Agreement, Altera MegaCore Function License 
# Agreement, or other applicable license agreement, including, 
# without limitation, that your use is for the sole purpose of 
# programming logic devices manufactured by Altera and sold by 
# Altera or its authorized distributors.  Please refer to the 
# applicable agreement for further details.
#
# -------------------------------------------------------------------------- #
#
# Quartus II 32-bit
# Version 12.0 Build 178 05/31/2012 SJ Web Edition
# Date created = 16:51:09  September 12, 2019
#
# -------------------------------------------------------------------------- #
#
# Notes:
#
# 1) The default values for assignments are stored in the file:
#		tiny_z80_assignment_defaults.qdf
#    If this file doesn't exist, see file:
#		assignment_defaults.qdf
#
# 2) Altera recommends that you do not modify this file. This
#    file is updated automatically by the Quartus II software
#    and any changes you make may be lost or overwritten.
#
# -------------------------------------------------------------------------- #


set_global_assignment -name FAMILY MAX7000AE
set_global_assignment -name DEVICE "EPM7064AETC44-10"
set_global_assignment -name TOP_LEVEL_ENTITY tiny_z80
set_global_assignment -name ORIGINAL_QUARTUS_VERSION 12.0
set_global_assignment -name PROJECT_CREATION_TIME_DATE "16:51:09  SEPTEMBER 12, 2019"
set_global_assignment -name LAST_QUARTUS_VERSION "13.0 SP1"
set_global_assignment -name ERROR_CHECK_FREQUENCY_DIVISOR "-1"
set_global_assignment -name MIN_CORE_JUNCTION_TEMP 0
set_global_assignment -name MAX_CORE_JUNCTION_TEMP 85
set_global_assignment -name EDA_SIMULATION_TOOL "ModelSim-Altera (VHDL)"
set_global_assignment -name EDA_OUTPUT_DATA_FORMAT VHDL -section_id eda_simulation
set_global_assignment -name VHDL_FILE tiny_z80_vhdl.vhd
set_global_assignment -name VHDL_FILE page_reg_4x6.vhd
set_global_assignment -name VHDL_FILE d_ff_rst_vhdl.vhd
set_global_assignment -name QIP_FILE page_reg_4x6_lpm.qip
set_global_assignment -name MAX7000_DEVICE_IO_STANDARD "3.3-V LVCMOS"
set_global_assignment -name USE_CONFIGURATION_DEVICE ON
set_location_assignment PIN_37 -to UART_CLK
set_location_assignment PIN_1 -to TDI
set_location_assignment PIN_38 -to M1
set_location_assignment PIN_44 -to A[2]
set_location_assignment PIN_34 -to WR
set_location_assignment PIN_7 -to TMS
set_location_assignment PIN_14 -to MA[15]
set_location_assignment PIN_8 -to A[7]
set_location_assignment PIN_11 -to D[1]
set_location_assignment PIN_3 -to A[4]
set_location_assignment PIN_35 -to CTC_CLK
set_location_assignment PIN_23 -to A[0]
set_location_assignment PIN_31 -to A_HI[14]
set_location_assignment PIN_21 -to MA[17]
set_location_assignment PIN_22 -to MA[18]
set_location_assignment PIN_25 -to A[1]
set_location_assignment PIN_12 -to D[2]
set_location_assignment PIN_19 -to D[4]
set_location_assignment PIN_6 -to A[6]
set_location_assignment PIN_5 -to A[5]
set_location_assignment PIN_26 -to TCK
set_location_assignment PIN_40 -to MREQ
set_location_assignment PIN_33 -to IORQ
set_location_assignment PIN_10 -to D[0]
set_location_assignment PIN_28 -to A_HI[15]
set_location_assignment PIN_32 -to TDO
set_location_assignment PIN_18 -to D[3]
set_location_assignment PIN_20 -to D[5]
set_location_assignment PIN_15 -to MA[16]
set_location_assignment PIN_39 -to RSTn
set_location_assignment PIN_2 -to A[3]
set_location_assignment PIN_13 -to MA[14]
set_location_assignment PIN_42 -to RAM_CSn
set_location_assignment PIN_43 -to ROM_CSn

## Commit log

2020-07-09 Add KiCad files and images
    [Tiny_Z80.kicad_pcb, Tiny_Z80.sch]
2020-07-14 README: Add connectors and jumpers documentation
2020-07-20 Move J7 reference so it does not overlap with 100nF value of C4
    [Tiny_Z80.kicad_pcb]
2020-07-20 Add Gerber files
    [Tiny_Z80-B_Cu.gbr, Tiny_Z80-B_Mask.gbr, Tiny_Z80-B_Paste.gbr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]

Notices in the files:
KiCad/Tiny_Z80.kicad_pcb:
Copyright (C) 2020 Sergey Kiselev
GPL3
